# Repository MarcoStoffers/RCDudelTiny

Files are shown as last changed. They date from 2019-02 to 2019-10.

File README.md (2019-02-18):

# RCDudelTiny
## MP3-Player control via RC
RCDudelTiny

- This board will control the following functions of a MP3-Player: ON / OFF | Play / Pause | Next / Previous | Volume + / -
- The functions will be controlled by only one RC channel. See my Youtube Video of my prototype for a short intro: https://youtu.be/fYEXbu7Ohzc

## Requirement
- A MP3-Player or MP3-board with 3.3 to 5.5V Power
- An amplifier with 1W - 50W regarding the used speaker
- Power supply for amplifier (the MP3-Player will be powered via the RC Receiver

## Connection
Have a look at the following pinout of the MP3-Player connector. A detailed Manual is also available (only german at this time) with lots of informations for building the RCDudelTiny and disassembling the MP3-Player
Connector

## 2 versions
There are two different Arduino Sketches in there: RCDudelTiny.ino is for a disassembled MP3-Player shown in the manual | RCDudelTiny-board.ino is for these ready MP3-boards including a 1W amplifier.
## Base
The module is based on a microchip ATtiny84A which is programmed via the [Arduino IDE](https://arduino.cc/). To use the microcontroller, the extension of [Spence Konde](https://github.com/SpenceKonde/ATTinyCore) is necessary. Programming is done without a bootloader directly via the ISP connector with an AVR programmer.

## License
The project is licensed under the Creative Common License. A rebuild for private or non-profit associations is desired, commercial rebuild or distribution I forbid. If someone should develop the mixer further, I ask for the naming of the original project.

CreativeCommonLicense

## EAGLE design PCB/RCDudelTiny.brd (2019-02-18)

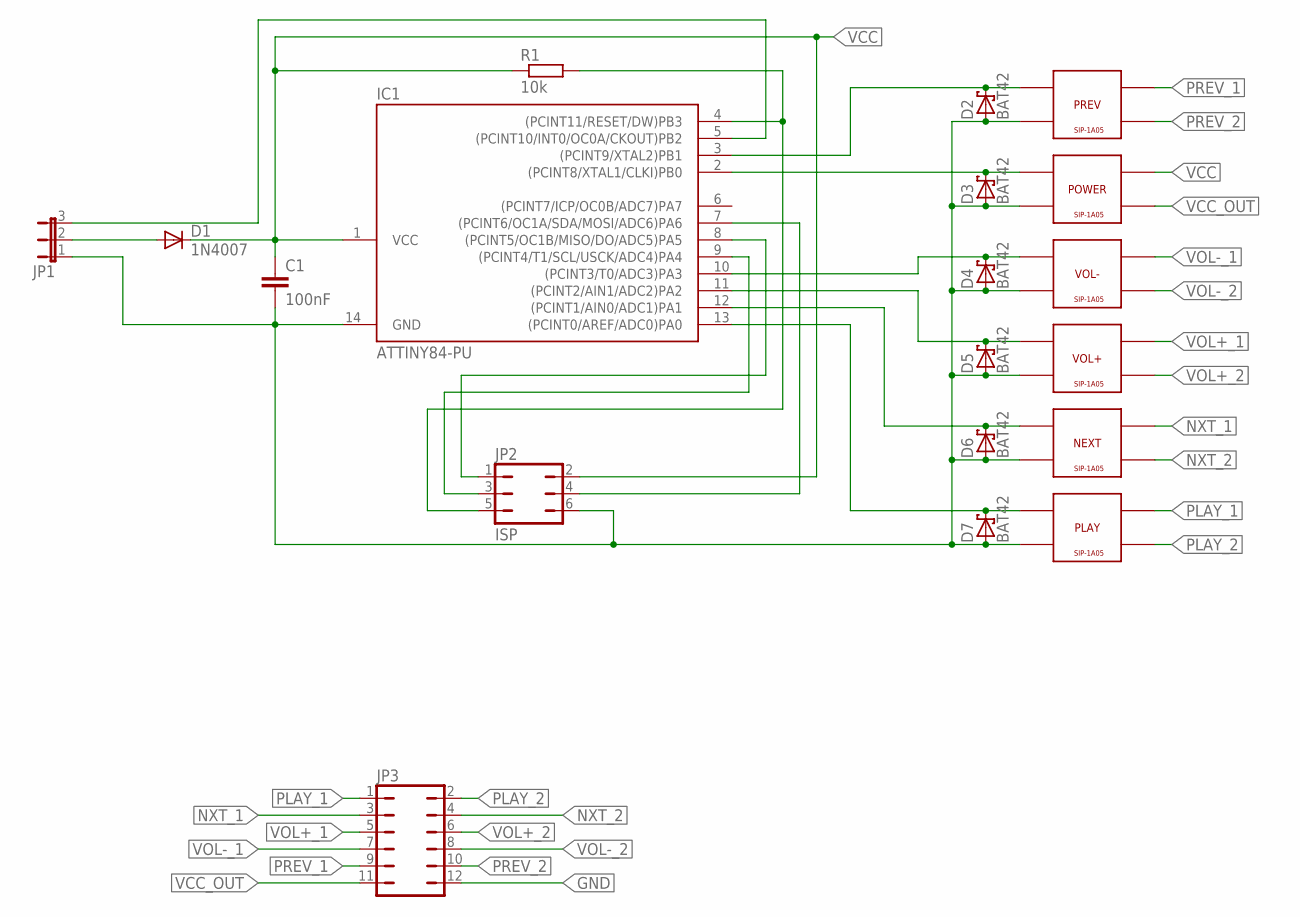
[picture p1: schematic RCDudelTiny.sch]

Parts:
C1: 100nF; C025-025X050
D1: 1N4007; DO41-10
D2, D3, D4, D5, D6, D7: BAT42; DO35-10
IC1: ATTINY84-PU; DIL14
JP1: JP2EJP2_OHNE_TEXT; JP2
JP2: ISP; JP3Q
JP3: JP6Q
NEXT: SIP1A05
PLAY: SIP1A05
POWER: SIP1A05
PREV: SIP1A05
R1: 10k; 0207/7
VOL+: SIP1A05
VOL-: SIP1A05

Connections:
GND: C1.2, D2.A, D3.A, D4.A, D5.A, D6.A, D7.A, IC1.14 (GND), JP1.1, JP2.6, JP3.12, NEXT.SP2, PLAY.SP2, POWER.SP2, PREV.SP2, VOL+.SP2, VOL-.SP2
unnamed: D1.A, JP1.2
unnamed: IC1.5 ((PCINT10/INT0/OC0A/CKOUT)PB2), JP1.3
unnamed: IC1.4 ((PCINT11/RESET/DW)PB3), JP2.5, R1.2
unnamed: IC1.8 ((PCINT5/OC1B/MISO/DO/ADC5)PA5), JP2.1
unnamed: IC1.9 ((PCINT4/T1/SCL/USCK/ADC4)PA4), JP2.3
unnamed: IC1.7 ((PCINT6/OC1A/SDA/MOSI/ADC6)PA6), JP2.4
unnamed: D2.C, IC1.3 ((PCINT9/XTAL2)PB1), PREV.SP1
unnamed: D3.C, IC1.2 ((PCINT8/XTAL1/CLKI)PB0), POWER.SP1
unnamed: D4.C, IC1.10 ((PCINT3/T0/ADC3)PA3), VOL-.SP1
unnamed: D5.C, IC1.11 ((PCINT2/AIN1/ADC2)PA2), VOL+.SP1
unnamed: D6.C, IC1.12 ((PCINT1/AIN0/ADC1)PA1), NEXT.SP1
unnamed: D7.C, IC1.13 ((PCINT0/AREF/ADC0)PA0), PLAY.SP1
NXT_1: JP3.3, NEXT.K1
NXT_2: JP3.4, NEXT.K2
PLAY_1: JP3.1, PLAY.K1
PLAY_2: JP3.2, PLAY.K2
PREV_1: JP3.9, PREV.K1
PREV_2: JP3.10, PREV.K2
VCC: C1.1, D1.C, IC1.1 (VCC), JP2.2, POWER.K1, R1.1
VCC_OUT: JP3.11, POWER.K2
VOL+_1: JP3.5, VOL+.K1
VOL+_2: JP3.6, VOL+.K2
VOL-_1: JP3.7, VOL-.K1
VOL-_2: JP3.8, VOL-.K2

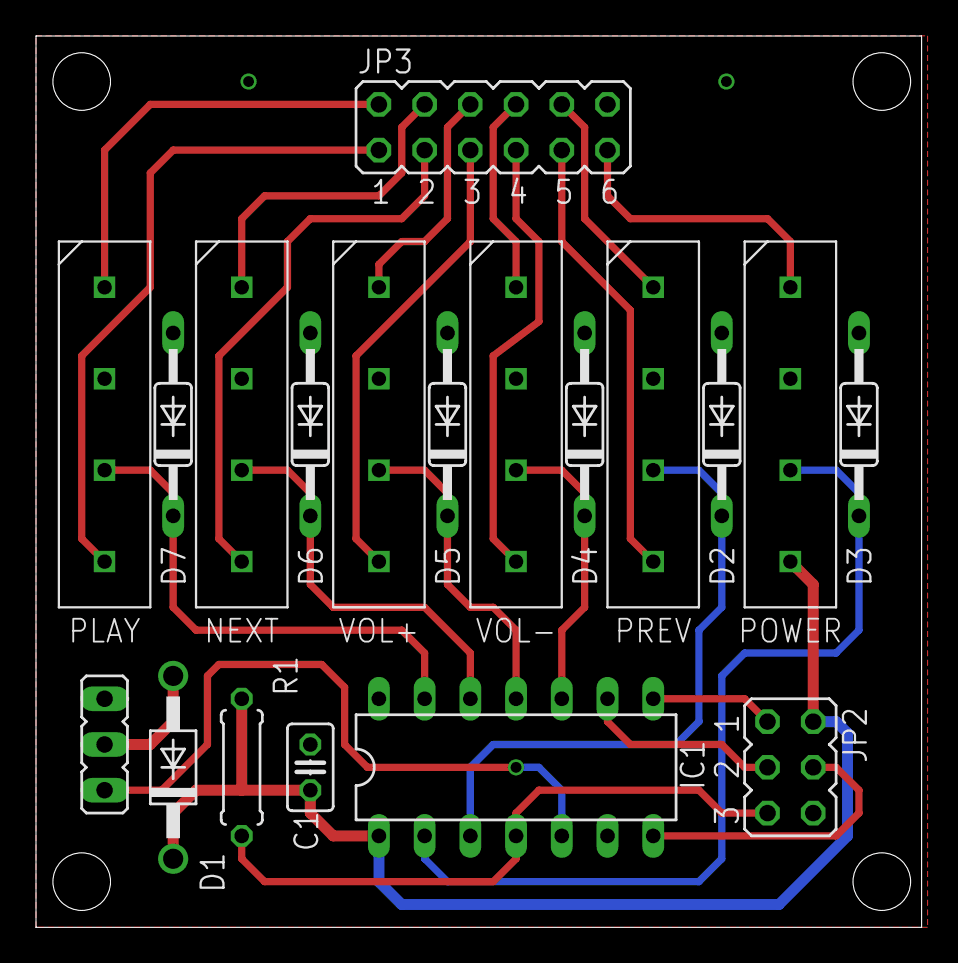
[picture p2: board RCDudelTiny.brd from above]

Board: 2 copper layers, 49.2 x 49.5 mm, 19 parts (0 on the bottom side), 25 nets.

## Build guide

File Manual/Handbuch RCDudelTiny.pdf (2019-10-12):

Marco Stoffers | Handbuch RCDudelTiny | 10/2019

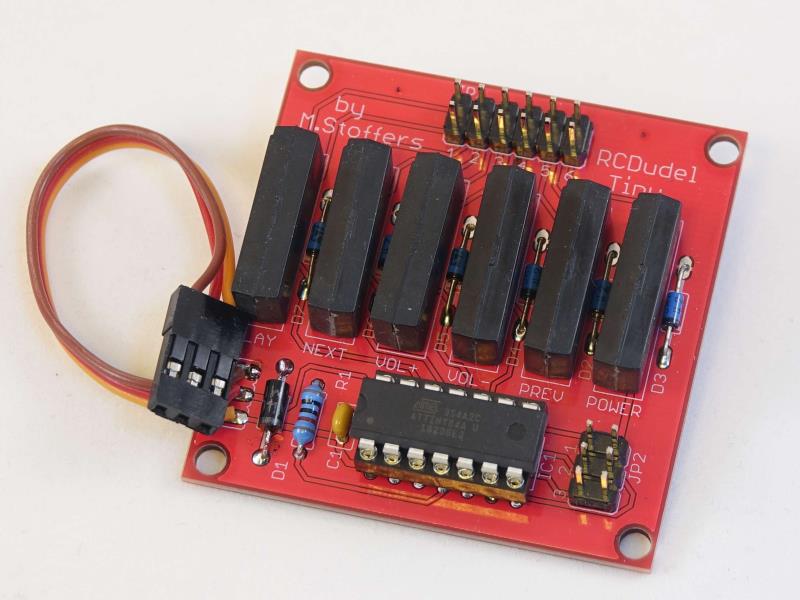
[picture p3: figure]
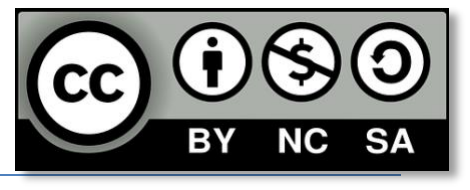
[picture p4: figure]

Seite 1

# Handbuch

# RCDudelTiny

Version: RCDudelTiny | 1.1
RCDudelTiny-board | B1.1

Seite 2

# Inhalt

- Funktion und Einsatzzweck | Seite 3
- Aufbau der Platine | Seite 3
- Demontage und Vorbereitung des MP3-Players | Seite 6
- Anlöten der Kabel am MP3-Player | Seite 9
- Alternative zum MP3-Player | Seite 10
- Anschluss des Players an die Platine | Seite 11
- Bedienung des RCDudelTiny | Seite 11

Begriffe und Abkürzungen die in diesem Handbuch verwendet werden:

- MP3 – Datenformat für Musik und Geräusche. Es findet eine Komprimierung statt, die auch Teile des Klangspektrums abschneiden. Es ist also ein verlustbehaftetes Format. Vorteile: durch die Komprimierung bekommt man wesentlich mehr Musik bzw. Geräusche auf ein Speichermedium
- SD-Card – Speicherkarte die in vielen Geräten zum Einsatz kommt (digitale Kamera, Aufnahmegerät). Es gibt unterschiedliche Formen und Ausführungen. Hier kommt eine µSD-Card zum Einsatz in der Ausführung SD-hc
- Reed-Relais – kleine Schalter, die über einen Elektromagneten einen magnetischen Kontakt auslösen. Vorteil sind die geringen Ströme um das Elektromagnetische Feld zu erzeugen und die geringe Bauform. Leider lassen sich hiermit nur Verbraucher bis ca. 500mA schalten.

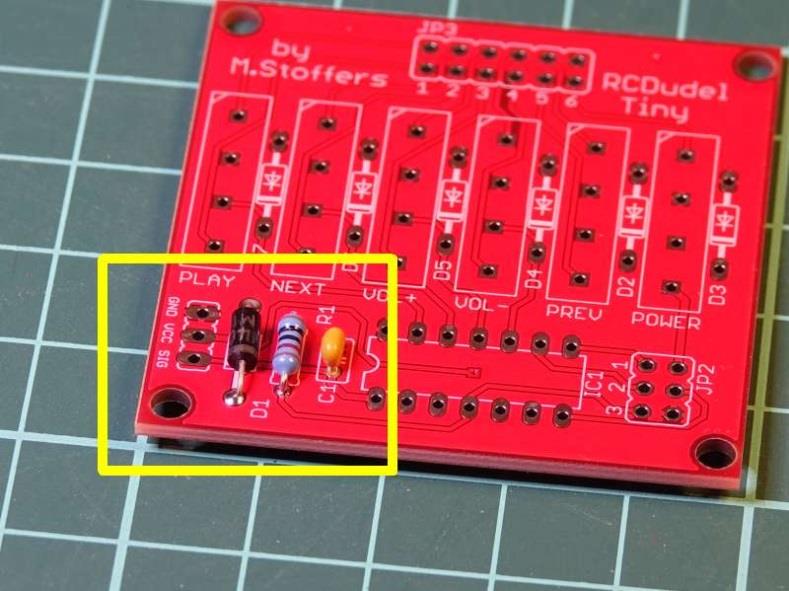
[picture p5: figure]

Seite 3

# Funktion und Einsatzzweck

Der RCDudelTiny ist eine Schaltung zur Ansteuerung eines MP3 Players mit Hilfe einer Fernsteuerung (RC). Die Schaltung simuliert Tastendrücke mit Hilfe von kleinen Reed-Relais und kann daher universell eingesetzt werden.

Primär ist die Ansteuerung eines MP3 Players angedacht. Mit der Änderung des Arduino Sketches kann aber auch eine Lichter-Steuerung für ein kleines Schiffsmodell daraus entstehen. Die Relais können bis zu 500mA bei 50V schalten. Das reicht für bis zu 10 LEDs pro Kanal.

Um die Schaltung leicht nachbaubar zu gestalten, werden nur bedrahtete Bauelemente verwendet – kein SMD. Durch den Einsatz einer professionell hergestellten Platine, gelingt der Nachbau auch ungeübteren Modellbauern.

Der RCDudelTiny wird direkt an einen freien Ausgang des Empfängers angeschlossen und bezieht daher auch seinen Strom und den für den MP3 Player (in Summer ca. 50-100mA). Dies muss bei der Empfängerstromversorgung beachtet werden.

# Aufbau der Platine

Die Platine ist einseitig gestaltet – alle Bauteile werden nur auf der Oberseite bestückt.

Schritt #1: Zuerst werden die Bauteile C1

(100nF), R1 (10kOhm) und D1 (1N4007) bestückt. Dazu die Beine der Bauteile abwinkeln (R1 & D1), in die markierten Öffnungen stecken und festlöten. Bei der Diode D1 muss darauf geachtet werden, dass die Markierung auf dem Bauteil (weißer Ring) mit dem Aufdruck auf der Platine übereinstimmt

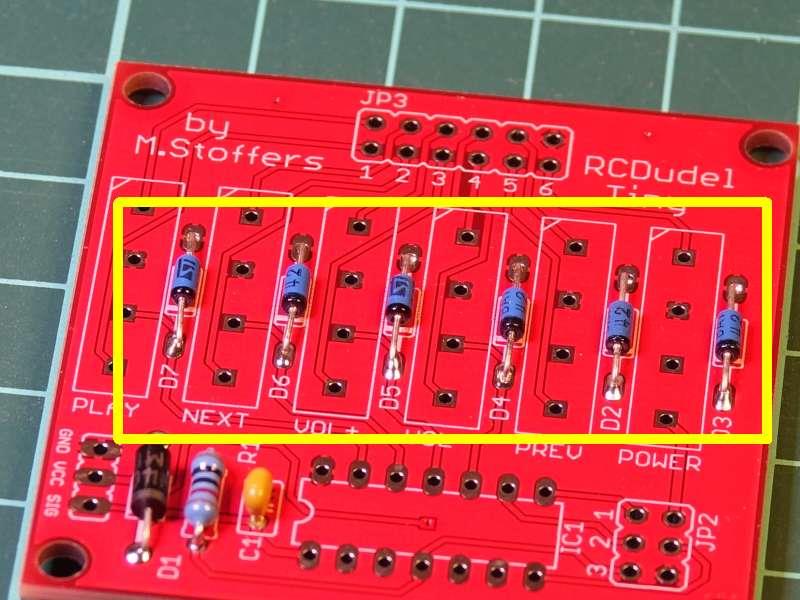
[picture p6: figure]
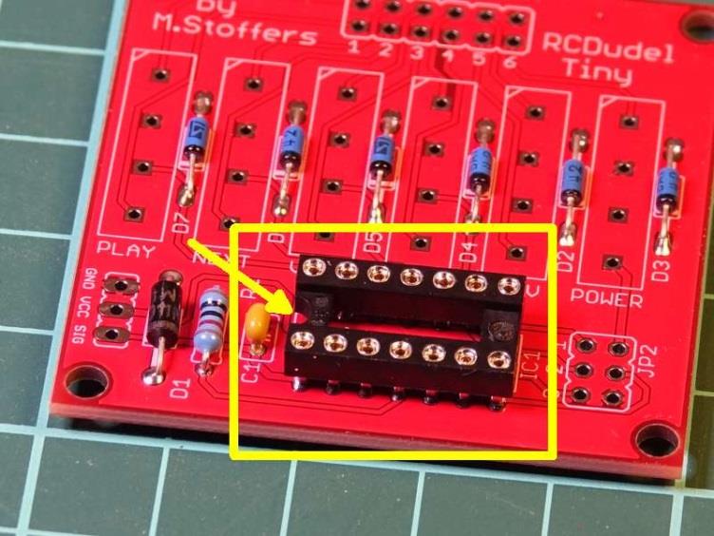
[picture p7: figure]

Seite 4

Schritt #2: Jetzt werden die Dioden D2-D7 (Bat42) bestückt. Auch hier ist wieder die Ausrichtung an Hand der Markierung am Bauteil und dem Aufdruck auf der Platine zu beachten.

Schritt #3: Der Sockel für den Mikrocontroller wird eingelötet. Zur besseren Orientierung sollte man die angebrachte Markierung an dem Sockel in die gleiche Richtung zeigen lassen wie auf dem Platinen Aufdruck.

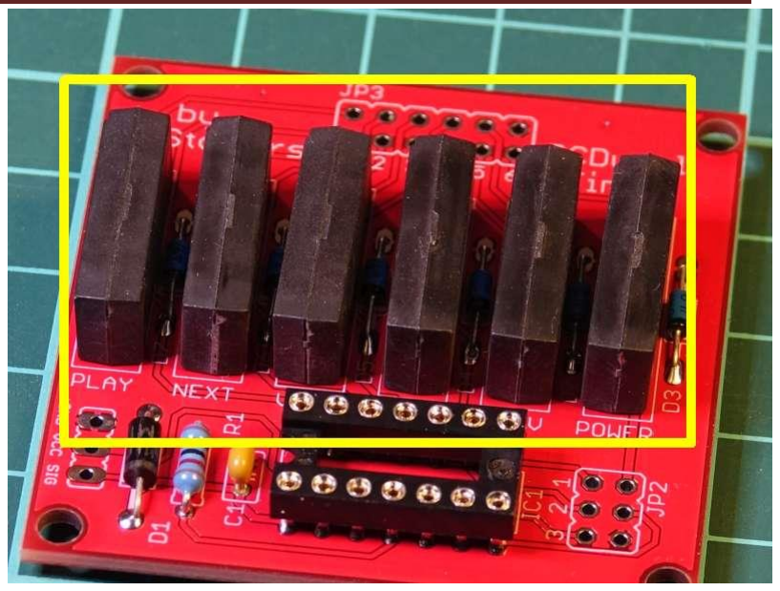
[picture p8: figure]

Seite 5

Schritt #4: Die Reed-Relais sind an der Reihe. Die Markierung auf den Relais müssen wieder mit denen auf der Platine übereinstimmen.

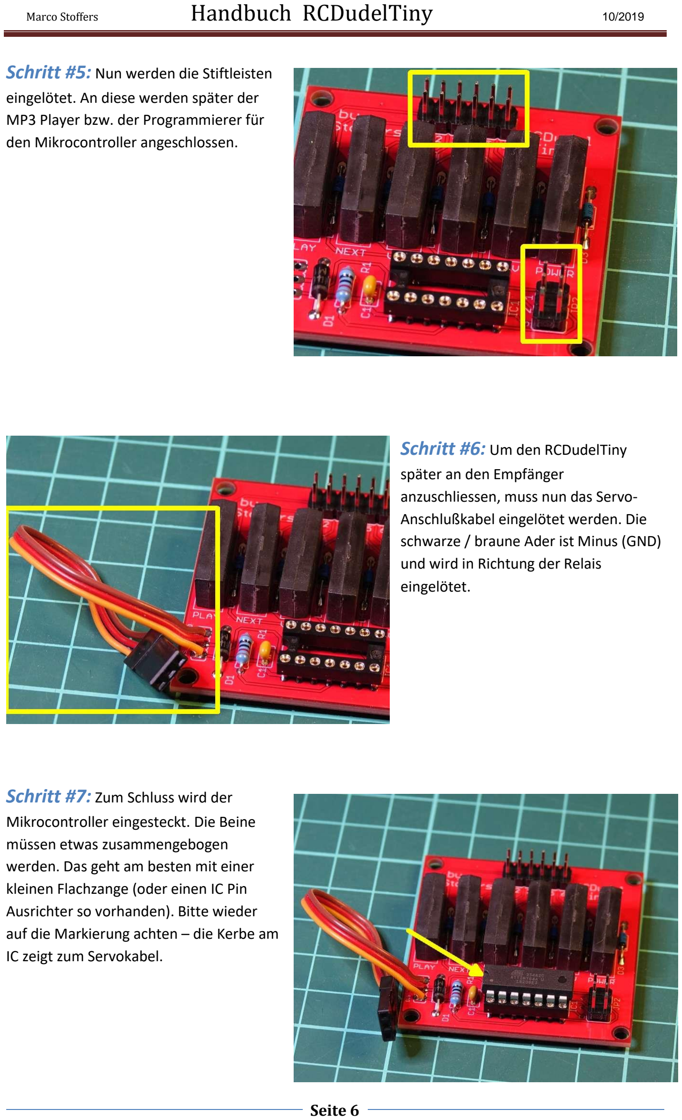
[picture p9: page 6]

Seite 6

Schritt #5: Nun werden die Stiftleisten eingelötet. An diese werden später der MP3 Player bzw. der Programmierer für den Mikrocontroller angeschlossen.

Schritt #6: Um den RCDudelTiny später an den Empfänger
anzuschliessen, muss nun das Servo-Anschlußkabel eingelötet werden. Die schwarze / braune Ader ist Minus (GND) und wird in Richtung der Relais eingelötet.

Schritt #7: Zum Schluss wird der Mikrocontroller eingesteckt. Die Beine müssen etwas zusammengebogen werden. Das geht am besten mit einer kleinen Flachzange (oder einen IC Pin Ausrichter so vorhanden). Bitte wieder auf die Markierung achten – die Kerbe am IC zeigt zum Servokabel.

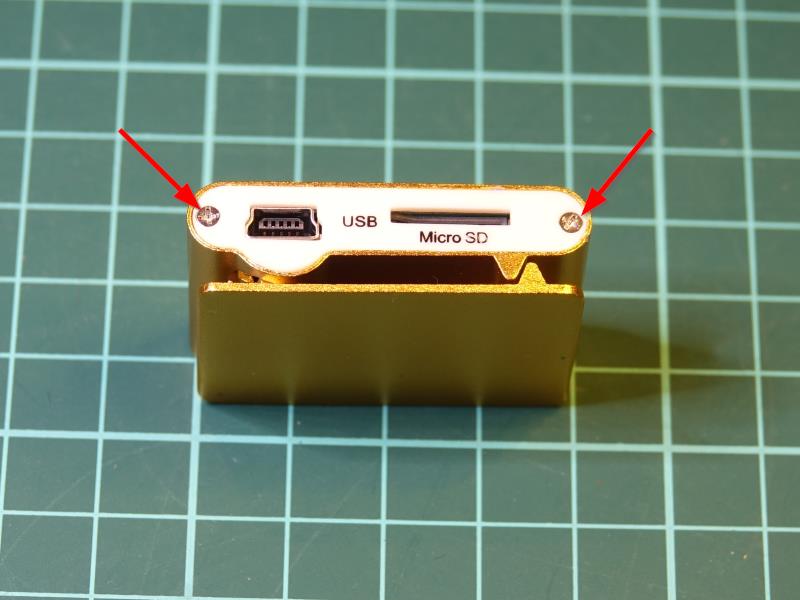
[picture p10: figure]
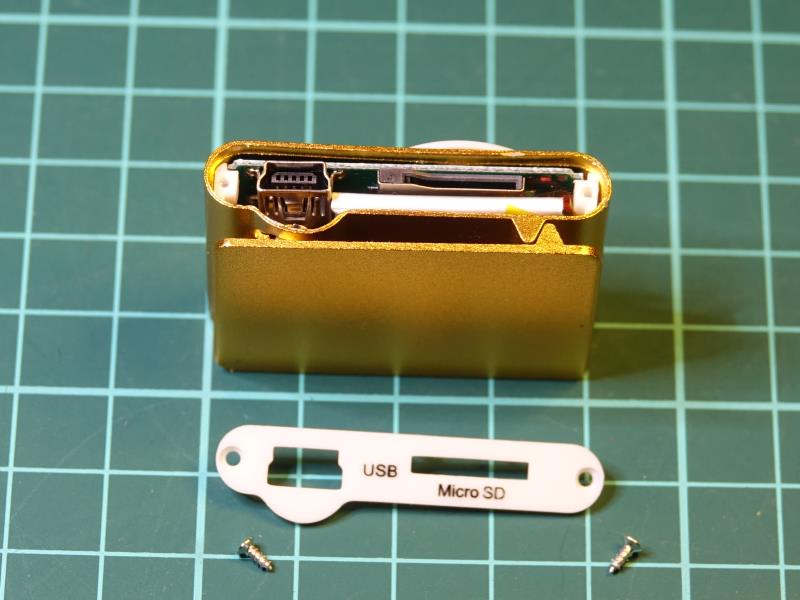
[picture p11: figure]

Seite 7

# Demontage und Vorbereitung des MP3-Players

Der hier verwendete MP3-Player sitzt in einem Metallgehäuse. Da wir an die Platine Kabel anlöten müssen, muss der Player komplett zerlegt werden.

Schritt #1: Mit einem kleinen

Kreuzschraubendreher werden die 2 kleinen Schrauben auf der Seite des USB-Anschlusses entfernt.

Schritt #2: Mit einem flachen, spitzen Gegenstand (Messer oder feiner Schlitzschraubendreher) wird die Plastik Frontplatte entfernt. Das geht am besten bei dem Einschub für die Speicherkarte.

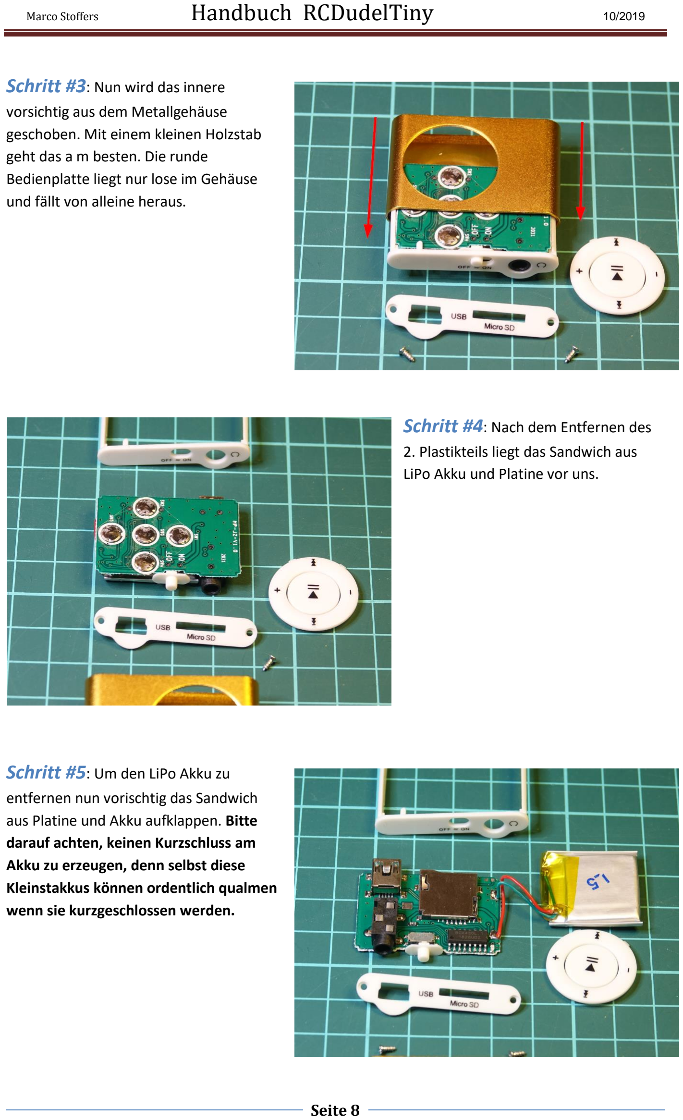
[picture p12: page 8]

Seite 8

Schritt #3: Nun wird das innere vorsichtig aus dem Metallgehäuse geschoben. Mit einem kleinen Holzstab geht das a m besten. Die runde Bedienplatte liegt nur lose im Gehäuse und fällt von alleine heraus.

Schritt #4: Nach dem Entfernen des
2. Plastikteils liegt das Sandwich aus LiPo Akku und Platine vor uns.

Schritt #5: Um den LiPo Akku zu entfernen nun vorischtig das Sandwich aus Platine und Akku aufklappen. Bitte darauf achten, keinen Kurzschluss am Akku zu erzeugen, denn selbst diese Kleinstakkus können ordentlich qualmen wenn sie kurzgeschlossen werden.

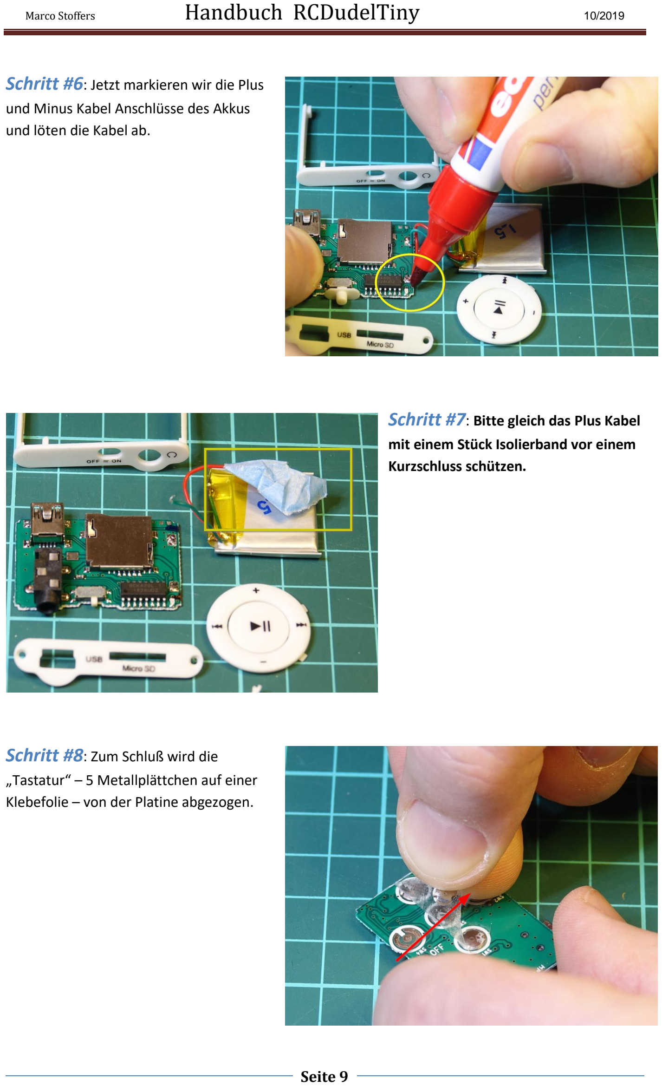
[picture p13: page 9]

Seite 9

Schritt #6: Jetzt markieren wir die Plus und Minus Kabel Anschlüsse des Akkus und löten die Kabel ab.

Schritt #7: Bitte gleich das Plus Kabel mit einem Stück Isolierband vor einem Kurzschluss schützen.

Schritt #8: Zum Schluß wird die „Tastatur“ – 5 Metallplättchen auf einer Klebefolie – von der Platine abgezogen.

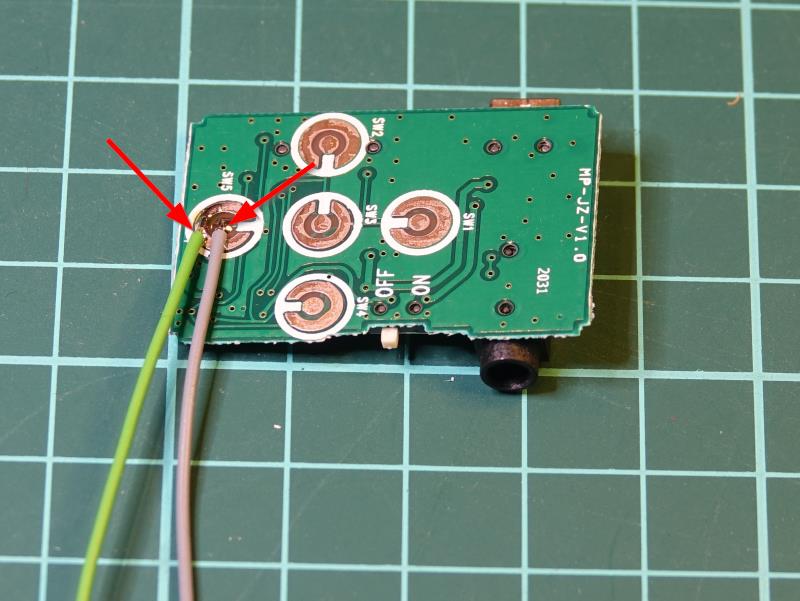
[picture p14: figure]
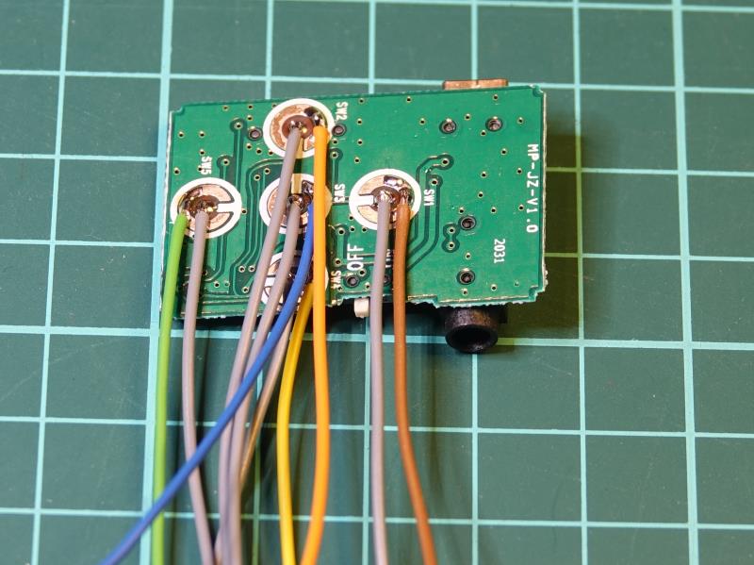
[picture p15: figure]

Seite
10

# Anlöten der Kabel am MP3-Player

Um die Verbindung vom MP3-Player zur Steuerplatine herzustellen, müssen an den Kontakten von den Tasten des Players Kabel angelötet werden.

Schritt #1: zuerst den mittleren

Kontakt des ganz linken Pads mit dem
Lötkolben verzinnen und ein dünnes Kabel vorverzinnen. Dann das Kabel anlöten. Ich habe an den mittleren Kontakten immer die gleiche Kabel-Farbe genutzt und die äußeren Ringe mit anderen Farben verbunden.

Schritt #2: Jetzt werden die übrigen

Kontakte verlötet. Immer darauf achten, dass keine Lötbrücken zwischen dem Mittelkontakt und dem Kontaktring entstehen.

Schritt #3: Zum Schluss werden noch die beiden markierten Anschlüssen auf der Oberseite

der Platine mit einem roten und einem schwarzen Kabel für die Stromversorgung versehen.

Ob man jetzt die Kabelenden direkt auf die Platine lötet oder wie auf der nächsten Seite zu sehen einen Stecker an-crimpt ist jedem selbst überlassen.

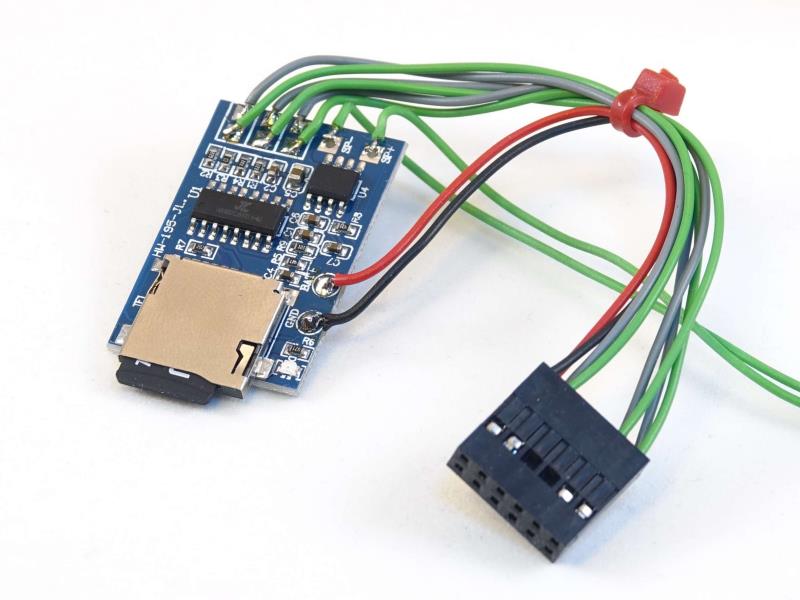
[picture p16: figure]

Seite
11

# Alternative zum MP3-Player

In diversen Online Handelsplattformen werden seit einiger Zeit sog. MP3-boards angeboten. Diese enthalten den gleichen Chip wie der MP3-Player, haben aber zusätzlich noch einen kleinen 1W-Verstärker auf der Platine. Klingt erst einmal sehr interessant, gerade für kleine Modelle.

Leider gibt es auch 2 Nachteile:
- Es gibt nur eine Stromversorgung. Da der Player bei Anlegen der Spannung sofort mit dem Abspielen des ersten Stückes anfängt, kann diese nicht dauerhaft aktiv bleiben. Der Verstärker bezieht seinen ganzen Strom (bis zu 350mA) auch aus eben diesen einen Anschluss. Es muss also sichergestellt sein, dass der Empfänger mit einer guten Stromversorgung ausgestattet ist (kein BEC)
- Die 3 Tasten-Anschlüsse auf der Platine sind doppelt belegt. Dadurch ändert sich die Ansteuerung. Ich habe dazu einen geänderten Arduino Sketch geschrieben: RCDudelTiny-board. Dieser ist ebenfalls in meinem GitHub Repository zu finden.

Seite
12

# Anschluss des Players an die Platine

Um nun den zerlegten MP3-Player oder das MP3-board an die Platine des RCDudelTiny anzuschließen, müssen wir noch die Anschlussbelegung kennen:

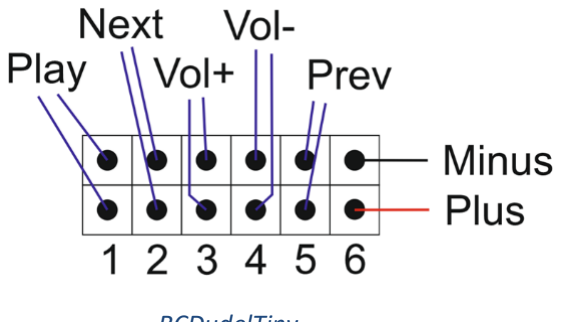
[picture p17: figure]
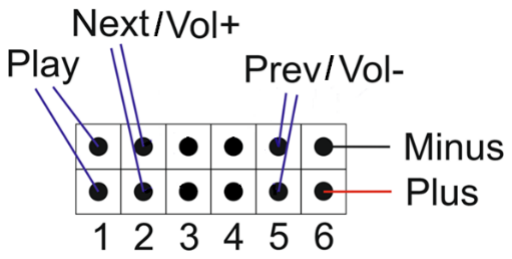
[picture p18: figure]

Die Zahlen stimmen mit denen auf der Platine überein. Bei dem Anschluss 6 & 6a (Plus & Minus) muss unbedingt auf die richtige Polung geachtet werden. Bei den anderen Anschlüssen ist diese egal, da die Relais eine Trennung zwischen Steuerung und Player vornehmen (sog. Galvanische Trennung).

# Bedienung des RCDudelTiny

Nach so viel Arbeit kommt nun das Vergnügen. Der RCDudelTiny wird an einem Kanal vom Empfänger angeschlossen, der Sender eingeschaltet und dann der Empfänger in Betrieb genommen. Wer schon einen Verstärker angeschlossen hat, schaltet diesen jetzt auch ein.

Bei der folgenden Funktionstabelle gehe ich davon aus, dass der RCDudelTiny an einem Kanal hängt, der am Sender einen Hebel mit vertikaler Bedienung (Oben, Mitte, Unten) hat.

- Hebel kurz nach oben: der MP3-Player schaltet sich ein und es wird das
erste Stück von der SD-Card wiedergegeben
- Hebel lange nach oben: die Lautstärke erhöht sich in 1s Schritten, bis der Hebel am Sender wieder losgelassen wird. Bei einem MP3-board erhöht sich die Lautstärke schneller. Dieses ist Programm technisch bedingt
- Hebel lange nach unten: die Lautstärke verringert sich in 1s Schritten, bis der Hebel wieder losgelassen wird. Auch bei dieser Funktion ist die Lautstärke Regelung am MP3-board schneller
- Hebel kurz nach unten: es wird zum nächsten Stück auf der Speicherkarte gesprungen
- Hebel 2x kurz nach unten: es wird zum vorherigen Stück gesprungen
- Hebel 2x kurz nach oben: der Player wird ausgeschaltet.
RCDudelTiny | RCDudelTiny-board

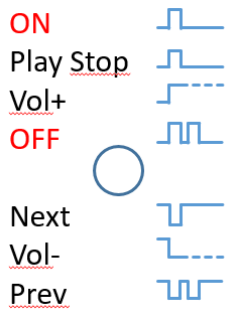
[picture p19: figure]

Schalterbeschriftung

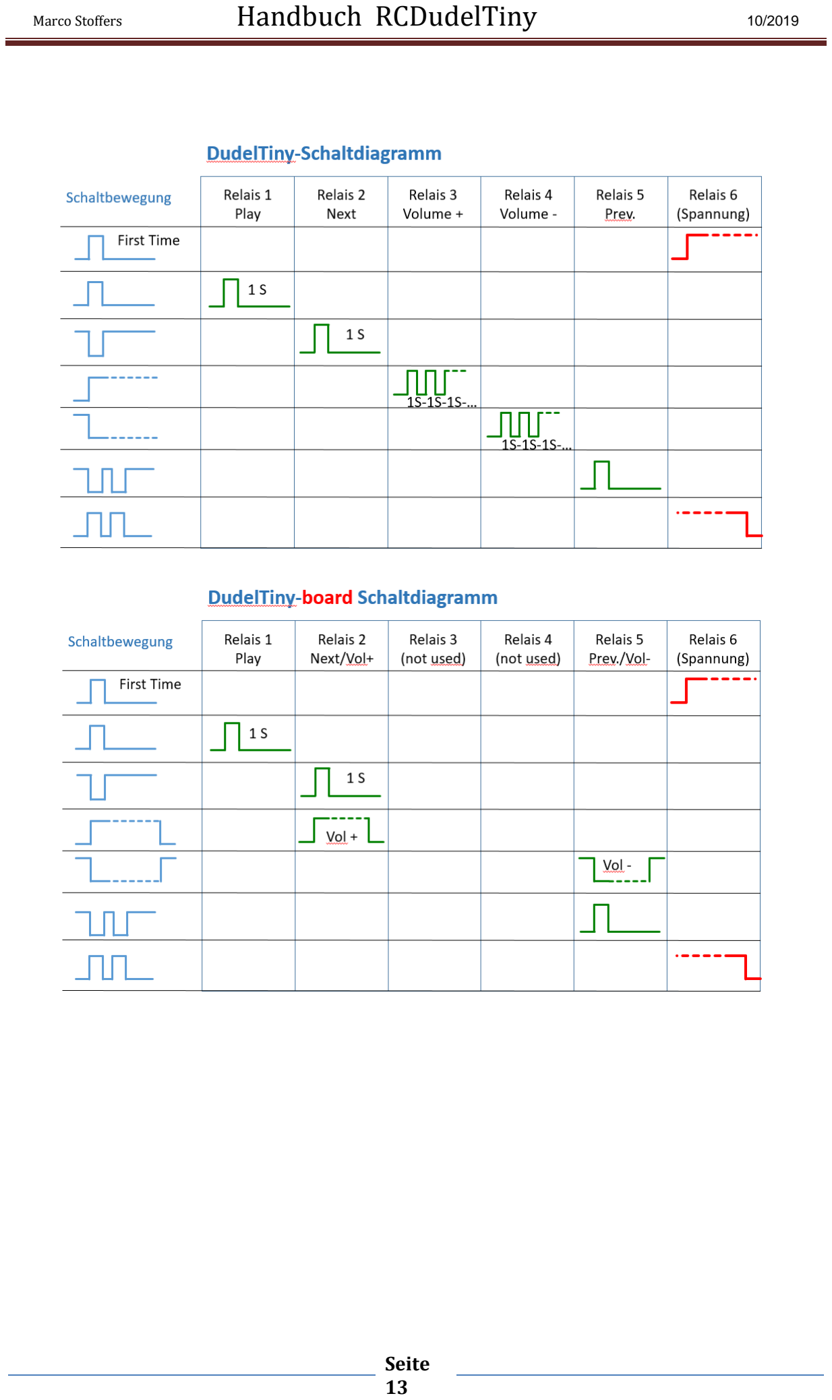
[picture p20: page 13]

Seite
13

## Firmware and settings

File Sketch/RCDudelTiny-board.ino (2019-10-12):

/*************************************************************************************
* RCDudelTiny 
* ============
* Steuerung eines MP3-Boards mit dem China IC GPD2806A und inkl. 1W Verstärker
*                 ==========                                     =============
* Version : B1.1 
* Hardware: ATtiny84A/8MHz internal | ATtiny Core von Spence Konde
* Author  : Marco Stoffers
* Year:   : 2018
* License : CC | BY, NC, SA
*
* Modifed : B1.1, 10/2019, by Juergen Overroedder | Saves the average value for reciever input only if this is between 1400 and 1600
************************************************************************************																  
* 
*
* Steuerung eines MP3-Boards mit dem China IC GPD2806A und inkl. 1W Verstärker:
* - Stick kurz nach oben = Power on / Play / Pause
* - Stick 2x kurz nach oben (innerhalb 1sec) = Power off
* - Stick lang nach oben = Lauter
* - Stick kurz nach unten = nächster Titel
* - Stick 2x kurz nach unten (innerhalb 1sec) = vorheriger Titel
* - Stick lang nach unten = Leiser
* 
* Bei RC-Signal Verlust schaltet der MP3-Player ab
* 
* Inputs:
* --------
* D8 = Receiver Input
* 
* Outputs:
* ---------
* D0  = Play/Pause Relais
* D1  = Next Relais
* D9  = Previous Relais
* D10 = Power Relais 
* 
*/
/*************************************************************************************
 * User Defines
 *************************************************************************************/
/*************************************************************************************
 * Defines
 *************************************************************************************/
#define Power 10
#define PlayPause 0
#define Next 1
#define Previous 9
#define receiver_pin 8
#define between(x, a, b)  (((a) <= (x)) && ((x) <= (b)))
/*************************************************************************************
 * Variables
 *************************************************************************************/
volatile boolean rc_ok=false;
boolean eingeschaltet=false,hold_up=false,hold_down=false,meassuring=false, Adj_Volume=false;
boolean marker_playpause=false,marker_nextprevious=false;
uint8_t outputs[4]={Power, PlayPause, Next, Previous};
uint8_t i,j,rc_avg_count=0;
volatile uint16_t rc_temp=0,rc_value=0;
uint16_t np_avg=0;
volatile uint32_t start_micros,stop_micros,micros_helper;
uint32_t rc_millis,playpause_millis=0,nextprevious_millis=0;
/*************************************************************************************
 * Setup
 *************************************************************************************/
void setup() {
  for(i=0;i<6;i++) {
    pinMode(outputs[i], OUTPUT);
    digitalWrite(outputs[i], LOW);
  }
  // Set Inputs
  pinMode(receiver_pin, INPUT);
  // enable Receiver input 
  delay(500); 
  attachInterrupt(0, receiver, CHANGE);
  // wait until RC input is ok
  while(!rc_ok) { }
  while(np_avg < 900){
  // learn RC middle
  // only when rc_value between 1400 and 1600
    if(between(rc_value, 1400, 1600)){
      for(i=0; i<10; i++) {
         np_avg += rc_value;
         delay(100);
      }
      np_avg = np_avg / 10;
    }
  }
}
/*************************************************************************************
 * Main Loop
 *************************************************************************************/
void loop() {
  // Stick nach oben
  if(rc_ok) {
    if(rc_value > np_avg + 250) {
      if(meassuring) {
        if(rc_millis < millis()) {
          digitalWrite(Next, HIGH);
          Adj_Volume=true;
          hold_up=false;
        }
        else hold_up=true;
      }
      else {
        meassuring=true;
        rc_millis=millis() + 750;
      }
    }
    // Stick nach unten
    else if(rc_value < np_avg - 250) {
      if(meassuring) {
        if(rc_millis < millis()) {
          digitalWrite(Previous, HIGH);
          Adj_Volume=true;
          hold_down=false;
        }
        else hold_down=true;
      }
      else {
        meassuring=true;
        rc_millis=millis() + 750;
      }
    }
    // Stick in der Mitte
    else {
      if(Adj_Volume) {
        digitalWrite(Next, LOW);
        digitalWrite(Previous, LOW);
        delay(100);
        Adj_Volume=false;
      }
      if(hold_up || marker_playpause) {
        Ein_Play_Pause();
      }
      if(hold_down || marker_nextprevious) {
        Naechster();
      }
      meassuring=false;
    }
  }
  else PowerOff();
}
/*************************************************************************************
 * Subroutine Einschalten, Play, Pause
 *************************************************************************************/
void Ein_Play_Pause() {
  if(!marker_playpause) {
    marker_playpause = true;
    playpause_millis = millis() + 1000;
    hold_up = false;
  }
  if((playpause_millis > millis()) && hold_up) {
    digitalWrite(Power, LOW);
    eingeschaltet=false;
    hold_up = false;
    marker_playpause = false;
  }
  if((playpause_millis < millis()) && !hold_up) {
    if(!eingeschaltet) {
      eingeschaltet = true;
      digitalWrite(Power, HIGH);
      marker_playpause = false;
    }
    else {
      digitalWrite(PlayPause, HIGH);
      delay(300);
      digitalWrite(PlayPause, LOW);
      marker_playpause = false;
    }
  }
}
/*************************************************************************************
 * Subroutine nächster Titel
 *************************************************************************************/
void Naechster() {
  if(!marker_nextprevious) {
    marker_nextprevious = true;
    nextprevious_millis = millis() + 1000;
    hold_down = false;
  }
  if((nextprevious_millis > millis()) && hold_down) {
    digitalWrite(Previous, HIGH);
    delay(300);
    digitalWrite(Previous, LOW);
    marker_nextprevious = false;
    hold_down = false;
  }
  if((nextprevious_millis < millis()) && !hold_down) {
    digitalWrite(Next, HIGH);
    delay(300);
    digitalWrite(Next, LOW);
    marker_nextprevious = false;
  }  
}
/*************************************************************************************
 * Subroutine Ausschalten MP3 Player
 *************************************************************************************/
void PowerOff() {
  digitalWrite(Power, LOW);
  eingeschaltet=false;  
}
/*************************************************************************************
 * Interrupt-subroutine to get Receiver Input
 *************************************************************************************/
void receiver() {
  micros_helper = micros();
  if(digitalRead(receiver_pin)) {
    start_micros = micros_helper;
  }
  else {
    stop_micros = micros_helper;
    if(start_micros < stop_micros) {
      rc_temp = rc_temp + (stop_micros - start_micros);
      rc_avg_count++;
    }
    // calculate average value of last 3 measurements and round to 10'er
    if(rc_avg_count > 2) {
      rc_value = rc_temp / 3;
      rc_value = ((rc_value/10)*10);
      rc_avg_count = 0;
      rc_temp = 0;
    }
    // check if value is correct
    if(between(rc_value, 900, 2100)) {
      rc_ok = true;
    }
    else rc_ok = false;
  }
}

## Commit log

2019-10-06 New Setup by Jürgen O. for better integration for FlySky transmitter (needs fix position of switches to initialize)
    [RCDudelTiny.ino]
2019-10-11 Add files via upload
    Additional information about the "-board" version
    Output overview for both versions.
2019-10-11 New Setup by Jürgen O. for better integration for FlySky transmitter …
    …(needs fix position of switches to initialize)
    Additional Information in Header About Version.
    [RCDudelTiny-board.ino, RCDudelTiny.ino]
